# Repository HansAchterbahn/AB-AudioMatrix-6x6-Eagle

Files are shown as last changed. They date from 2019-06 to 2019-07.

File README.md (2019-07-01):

# Audio Matrix Emmelie v3.2

Active audio matrix (6x6), which can map 6 input channels to 6 output channels. Connection via 3.5 jack cable. Compatible with line signals (aux, headphones, active speakers, ...).

*Fork me and have fun!*

## Pictures

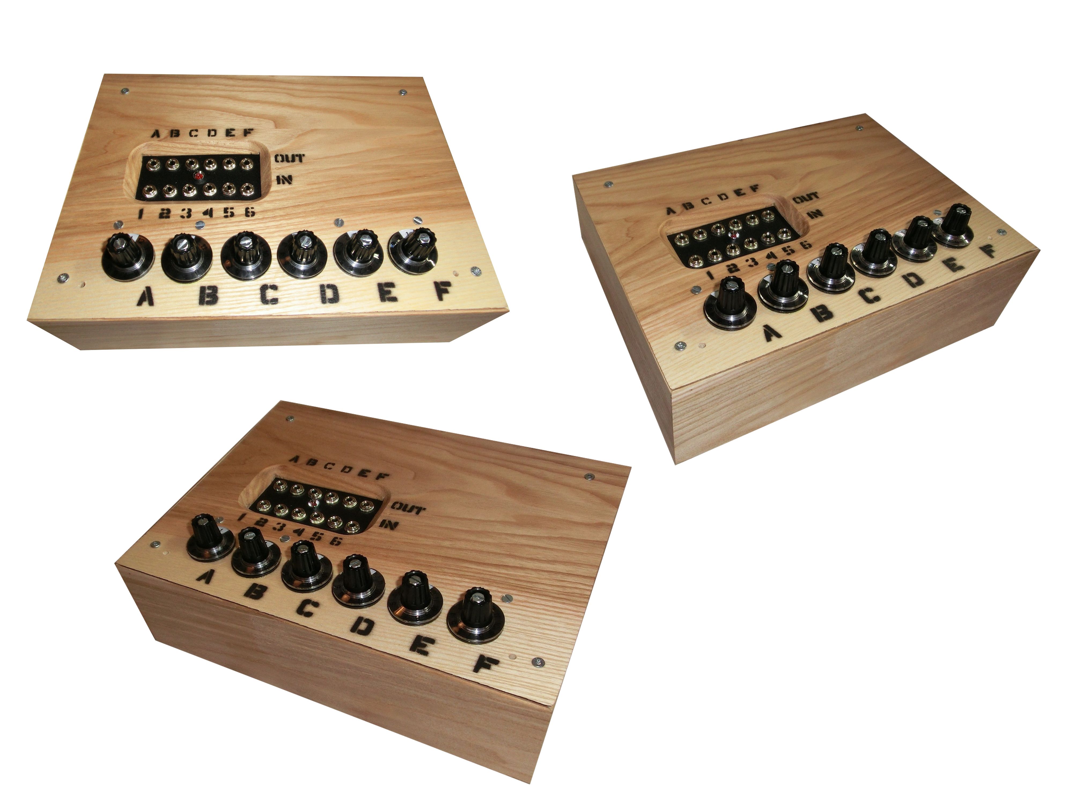
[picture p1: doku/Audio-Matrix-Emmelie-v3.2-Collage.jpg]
Foto: Collage Audio Matrix


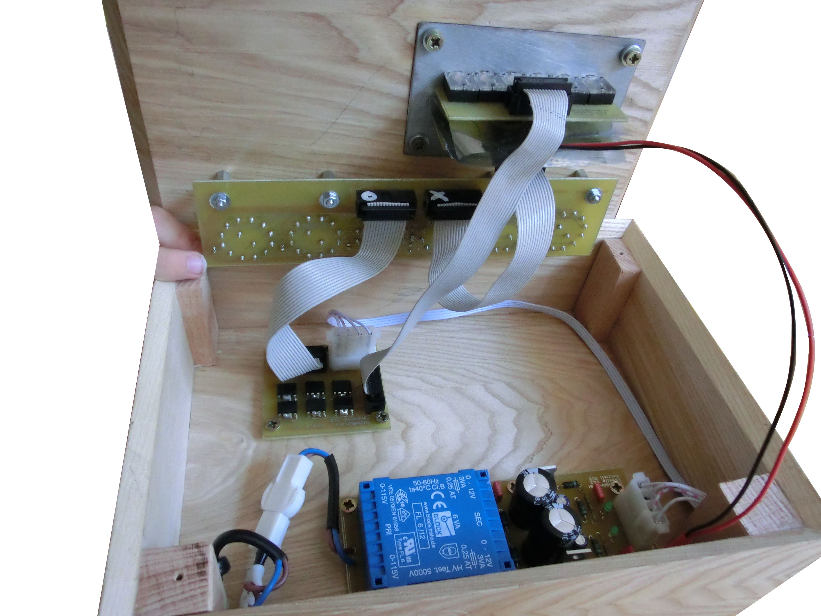
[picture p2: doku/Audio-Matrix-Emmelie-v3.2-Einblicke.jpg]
Foto: Das innere der Audio Matrix


## Schematic

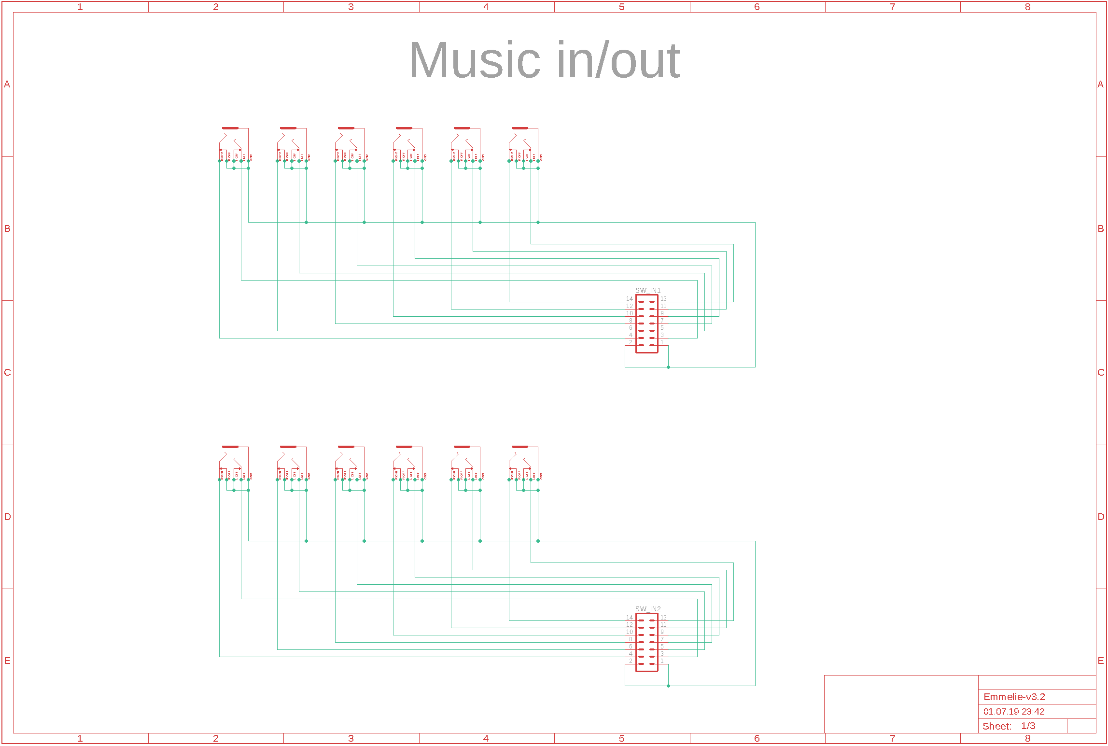
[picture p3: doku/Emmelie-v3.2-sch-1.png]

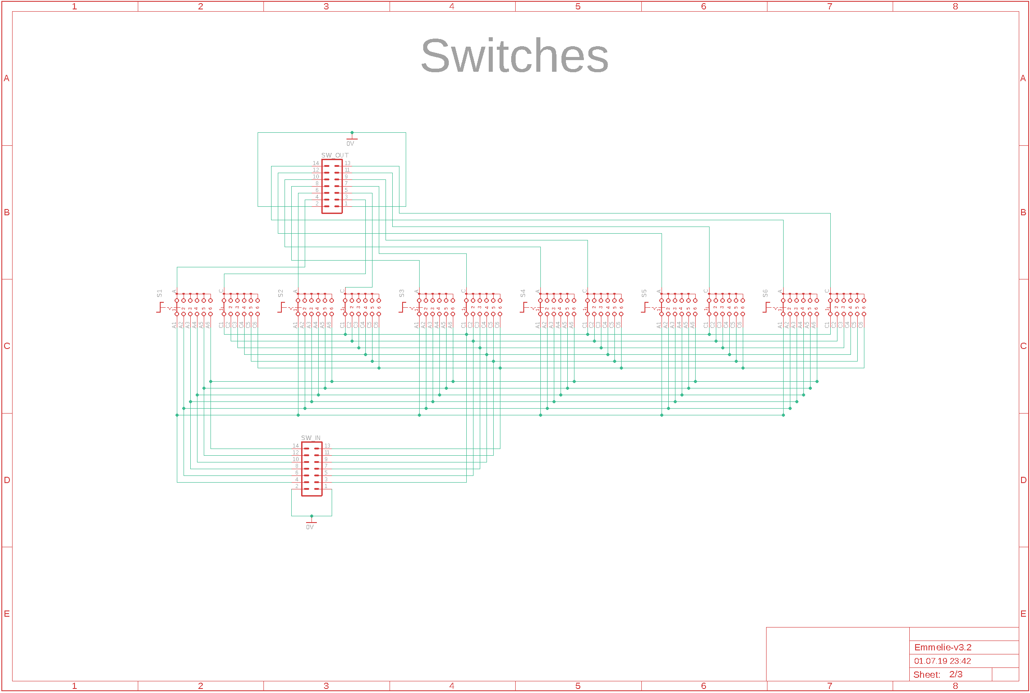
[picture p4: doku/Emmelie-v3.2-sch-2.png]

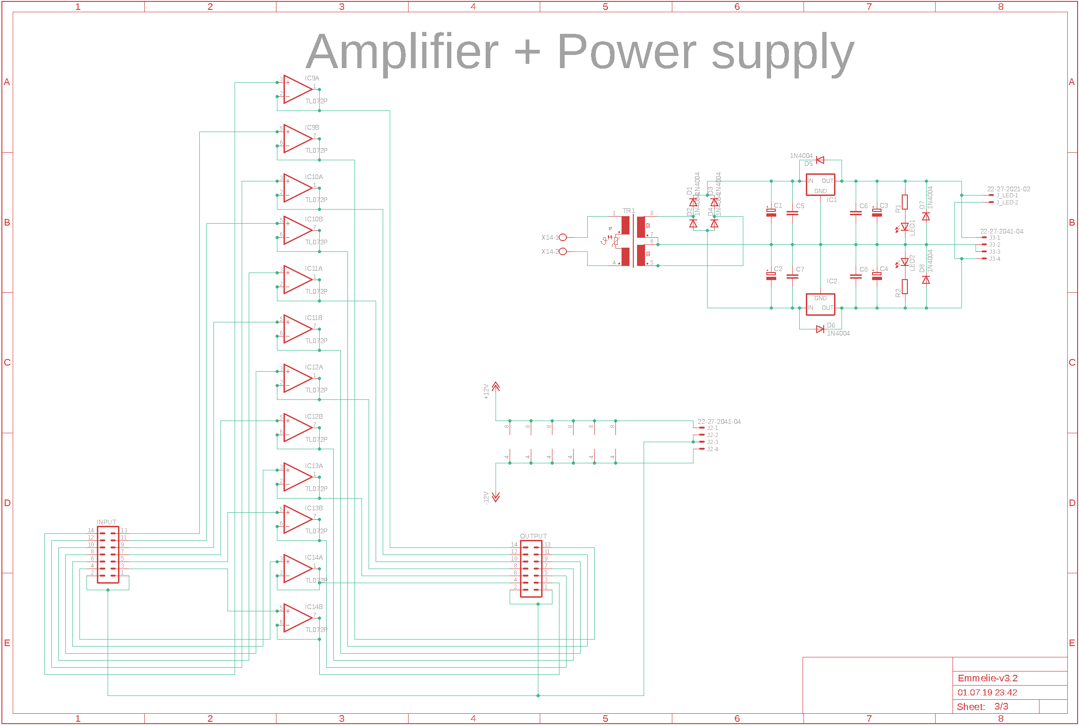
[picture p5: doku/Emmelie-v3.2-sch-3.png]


## Board

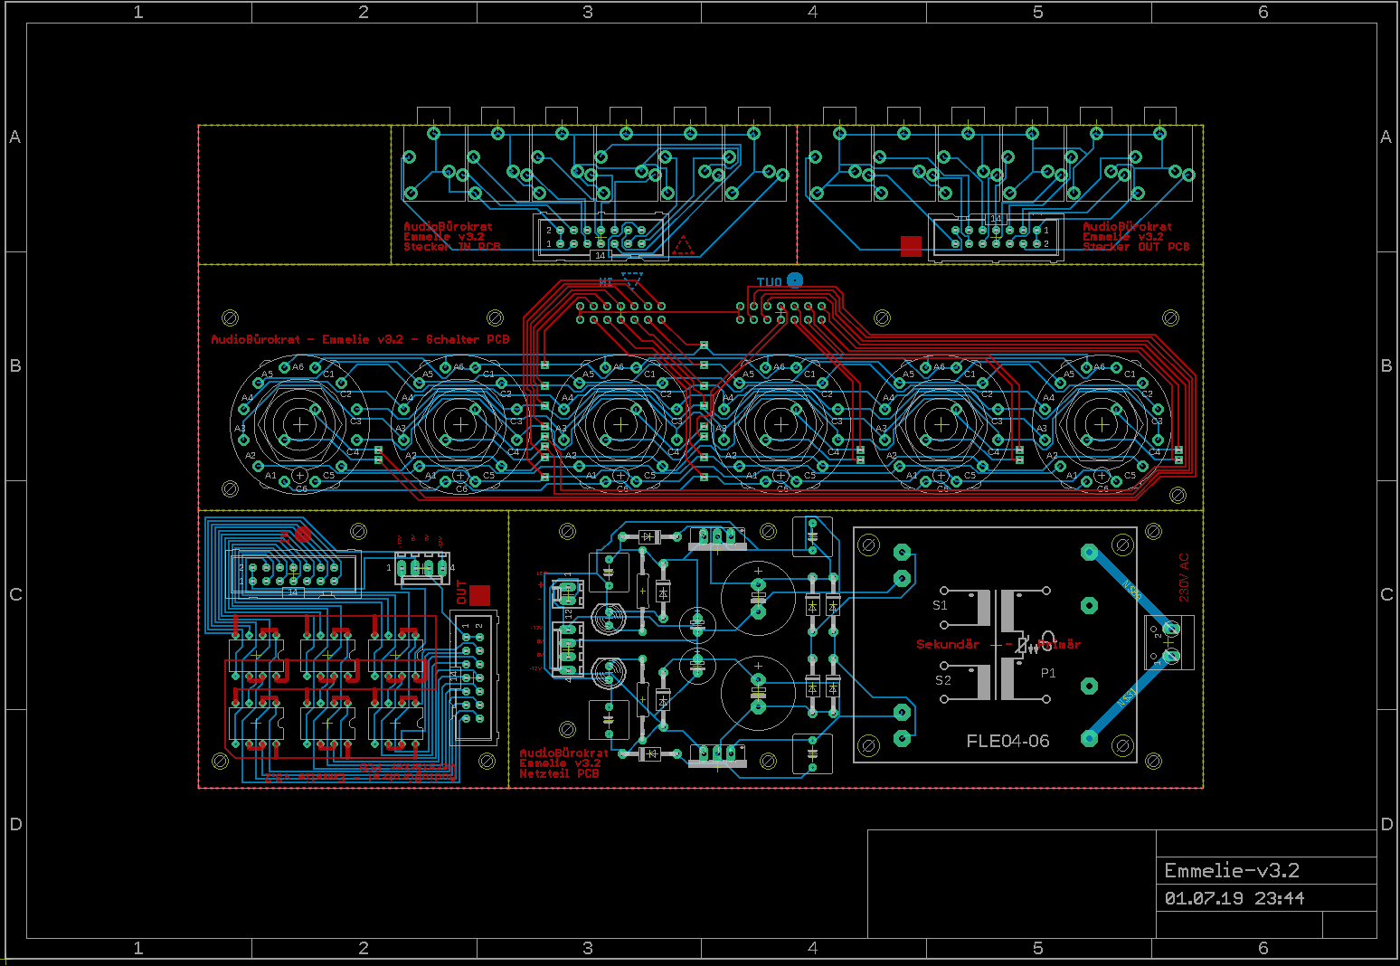
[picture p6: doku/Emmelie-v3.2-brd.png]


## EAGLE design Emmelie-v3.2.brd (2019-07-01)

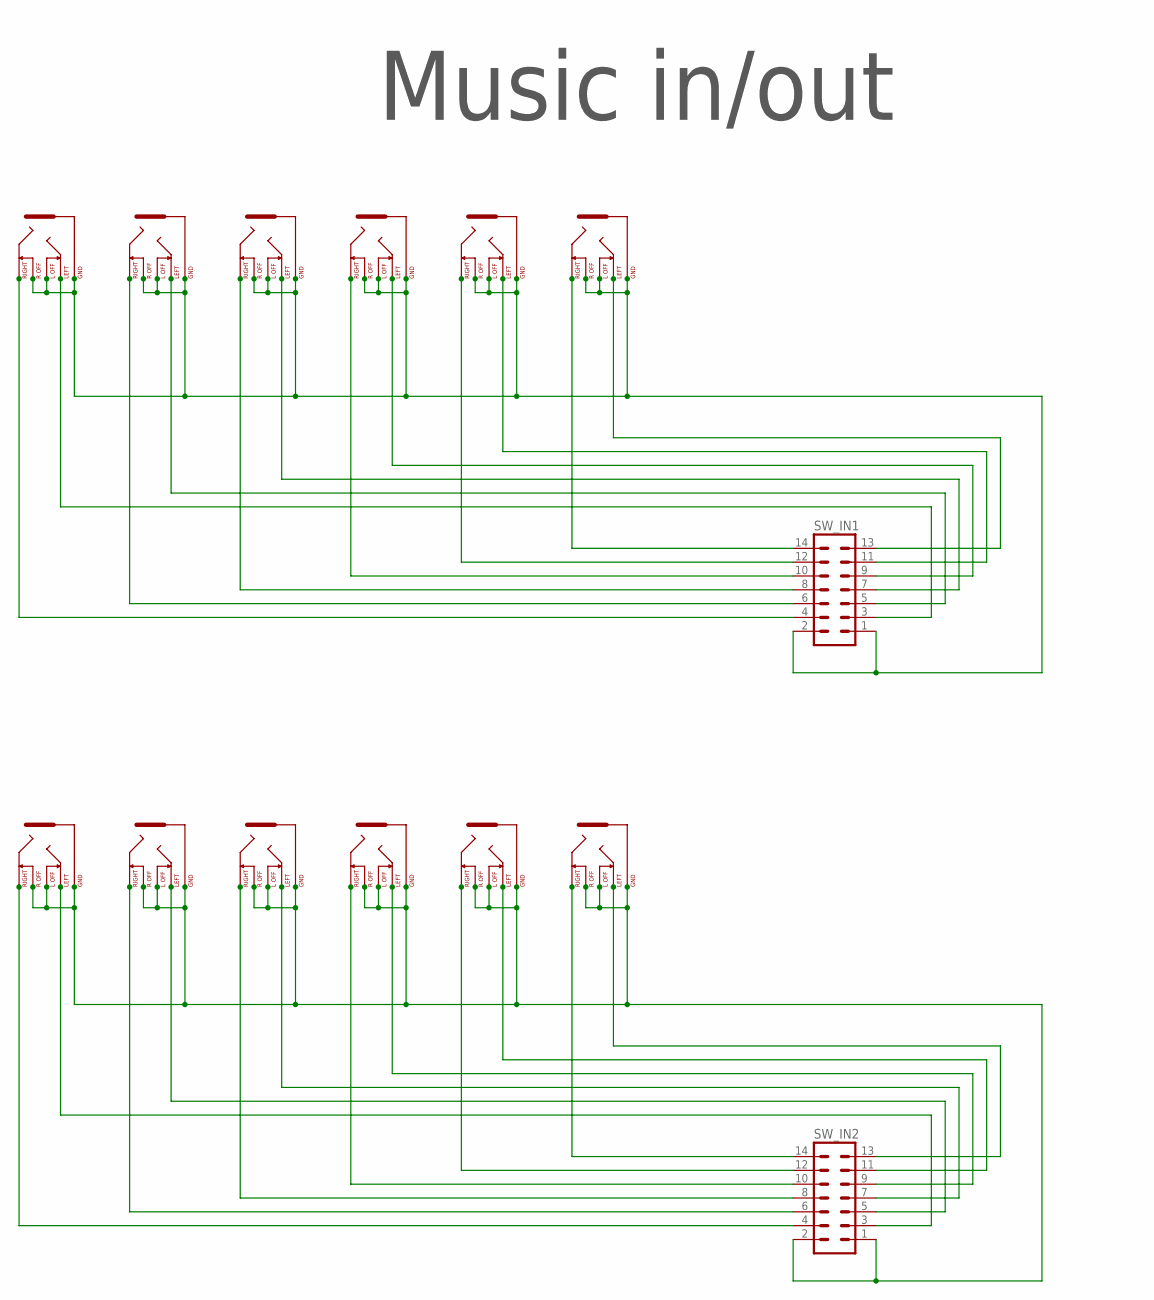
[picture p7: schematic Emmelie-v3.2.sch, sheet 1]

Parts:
SW_IN1, SW_IN2: ML14
U$1, U$2, U$3, U$4, U$5, U$6, U$7, U$8, U$9, U$10, U$11, U$12: KLINKE3,5

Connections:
KLINKE_IN_0V: SW_IN2.1, SW_IN2.2, U$7.GND, U$7.LEFT_OFF, U$7.RIGHT_OFF, U$8.GND, U$8.LEFT_OFF, U$8.RIGHT_OFF, U$9.GND, U$9.LEFT_OFF, U$9.RIGHT_OFF, U$10.GND, U$10.LEFT_OFF, U$10.RIGHT_OFF, U$11.GND, U$11.LEFT_OFF, U$11.RIGHT_OFF, U$12.GND, U$12.LEFT_OFF, U$12.RIGHT_OFF
KLINKE_OUT_0V: SW_IN1.1, SW_IN1.2, U$1.GND, U$1.LEFT_OFF, U$1.RIGHT_OFF, U$2.GND, U$2.LEFT_OFF, U$2.RIGHT_OFF, U$3.GND, U$3.LEFT_OFF, U$3.RIGHT_OFF, U$4.GND, U$4.LEFT_OFF, U$4.RIGHT_OFF, U$5.GND, U$5.LEFT_OFF, U$5.RIGHT_OFF, U$6.GND, U$6.LEFT_OFF, U$6.RIGHT_OFF
unnamed: SW_IN1.4, U$1.RIGHT
unnamed: SW_IN1.6, U$2.RIGHT
unnamed: SW_IN1.8, U$3.RIGHT
unnamed: SW_IN1.10, U$4.RIGHT
unnamed: SW_IN1.12, U$5.RIGHT
unnamed: SW_IN1.14, U$6.RIGHT
unnamed: SW_IN1.3, U$1.LEFT
unnamed: SW_IN1.5, U$2.LEFT
unnamed: SW_IN1.7, U$3.LEFT
unnamed: SW_IN1.9, U$4.LEFT
unnamed: SW_IN1.11, U$5.LEFT
unnamed: SW_IN1.13, U$6.LEFT
unnamed: SW_IN2.4, U$7.RIGHT
unnamed: SW_IN2.6, U$8.RIGHT
unnamed: SW_IN2.8, U$9.RIGHT
unnamed: SW_IN2.10, U$10.RIGHT
unnamed: SW_IN2.12, U$11.RIGHT
unnamed: SW_IN2.14, U$12.RIGHT
unnamed: SW_IN2.3, U$7.LEFT
unnamed: SW_IN2.5, U$8.LEFT
unnamed: SW_IN2.7, U$9.LEFT
unnamed: SW_IN2.9, U$10.LEFT
unnamed: SW_IN2.11, U$11.LEFT
unnamed: SW_IN2.13, U$12.LEFT

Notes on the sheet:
Music in/out

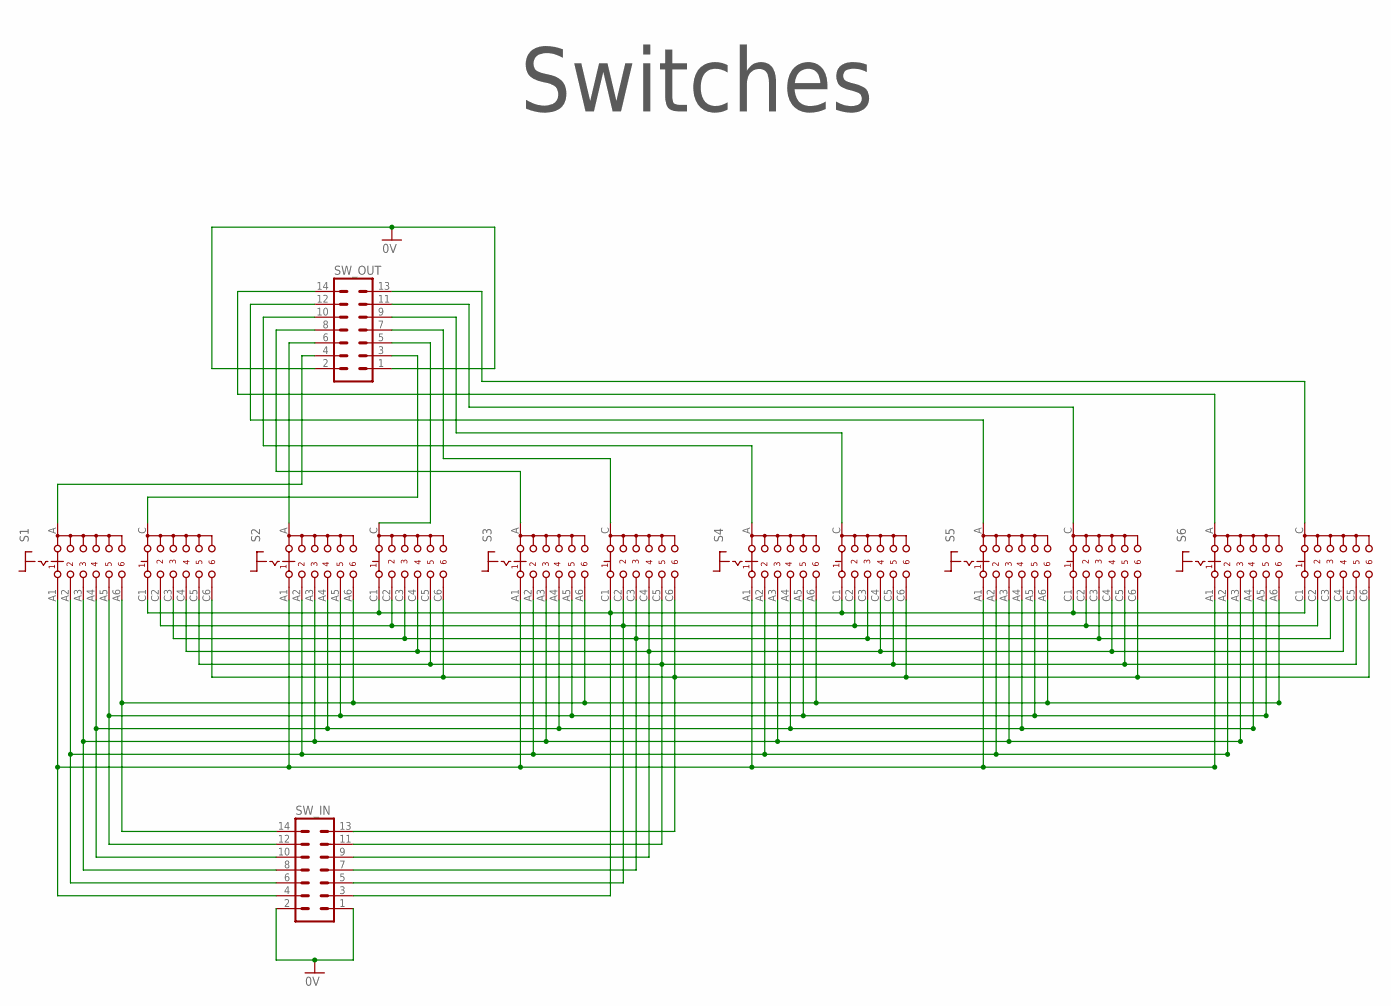
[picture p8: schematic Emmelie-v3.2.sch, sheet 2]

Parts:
S1, S2, S3, S4, S5, S6: CK102X06
SW_IN: ML14
SW_OUT: ML14

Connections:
unnamed: S1.A1, S2.A1, S3.A1, S4.A1, S5.A1, S6.A1, SW_IN.4
unnamed: S1.A2, S2.A2, S3.A2, S4.A2, S5.A2, S6.A2, SW_IN.6
unnamed: S1.A3, S2.A3, S3.A3, S4.A3, S5.A3, S6.A3, SW_IN.8
unnamed: S1.A4, S2.A4, S3.A4, S4.A4, S5.A4, S6.A4, SW_IN.10
unnamed: S1.A5, S2.A5, S3.A5, S4.A5, S5.A5, S6.A5, SW_IN.12
unnamed: S1.A6, S2.A6, S3.A6, S4.A6, S5.A6, S6.A6, SW_IN.14
unnamed: S1.C, SW_OUT.3
unnamed: S1.A, SW_OUT.4
unnamed: S2.A, SW_OUT.6
unnamed: S2.C, SW_OUT.5
unnamed: S3.A, SW_OUT.8
unnamed: S3.C, SW_OUT.7
unnamed: S4.A, SW_OUT.10
unnamed: S4.C, SW_OUT.9
unnamed: S5.A, SW_OUT.12
unnamed: S5.C, SW_OUT.11
unnamed: S6.A, SW_OUT.14
unnamed: S6.C, SW_OUT.13
unnamed: S1.C1, S2.C1, S3.C1, S4.C1, S5.C1, S6.C1, SW_IN.3
unnamed: S1.C2, S2.C2, S3.C2, S4.C2, S5.C2, S6.C2, SW_IN.5
unnamed: S1.C3, S2.C3, S3.C3, S4.C3, S5.C3, S6.C3, SW_IN.7
unnamed: S1.C4, S2.C4, S3.C4, S4.C4, S5.C4, S6.C4, SW_IN.9
unnamed: S1.C5, S2.C5, S3.C5, S4.C5, S5.C5, S6.C5, SW_IN.11
unnamed: S1.C6, S2.C6, S3.C6, S4.C6, S5.C6, S6.C6, SW_IN.13
SCHALTER_0V: SW_IN.1, SW_IN.2, SW_OUT.1, SW_OUT.2

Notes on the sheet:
Switches

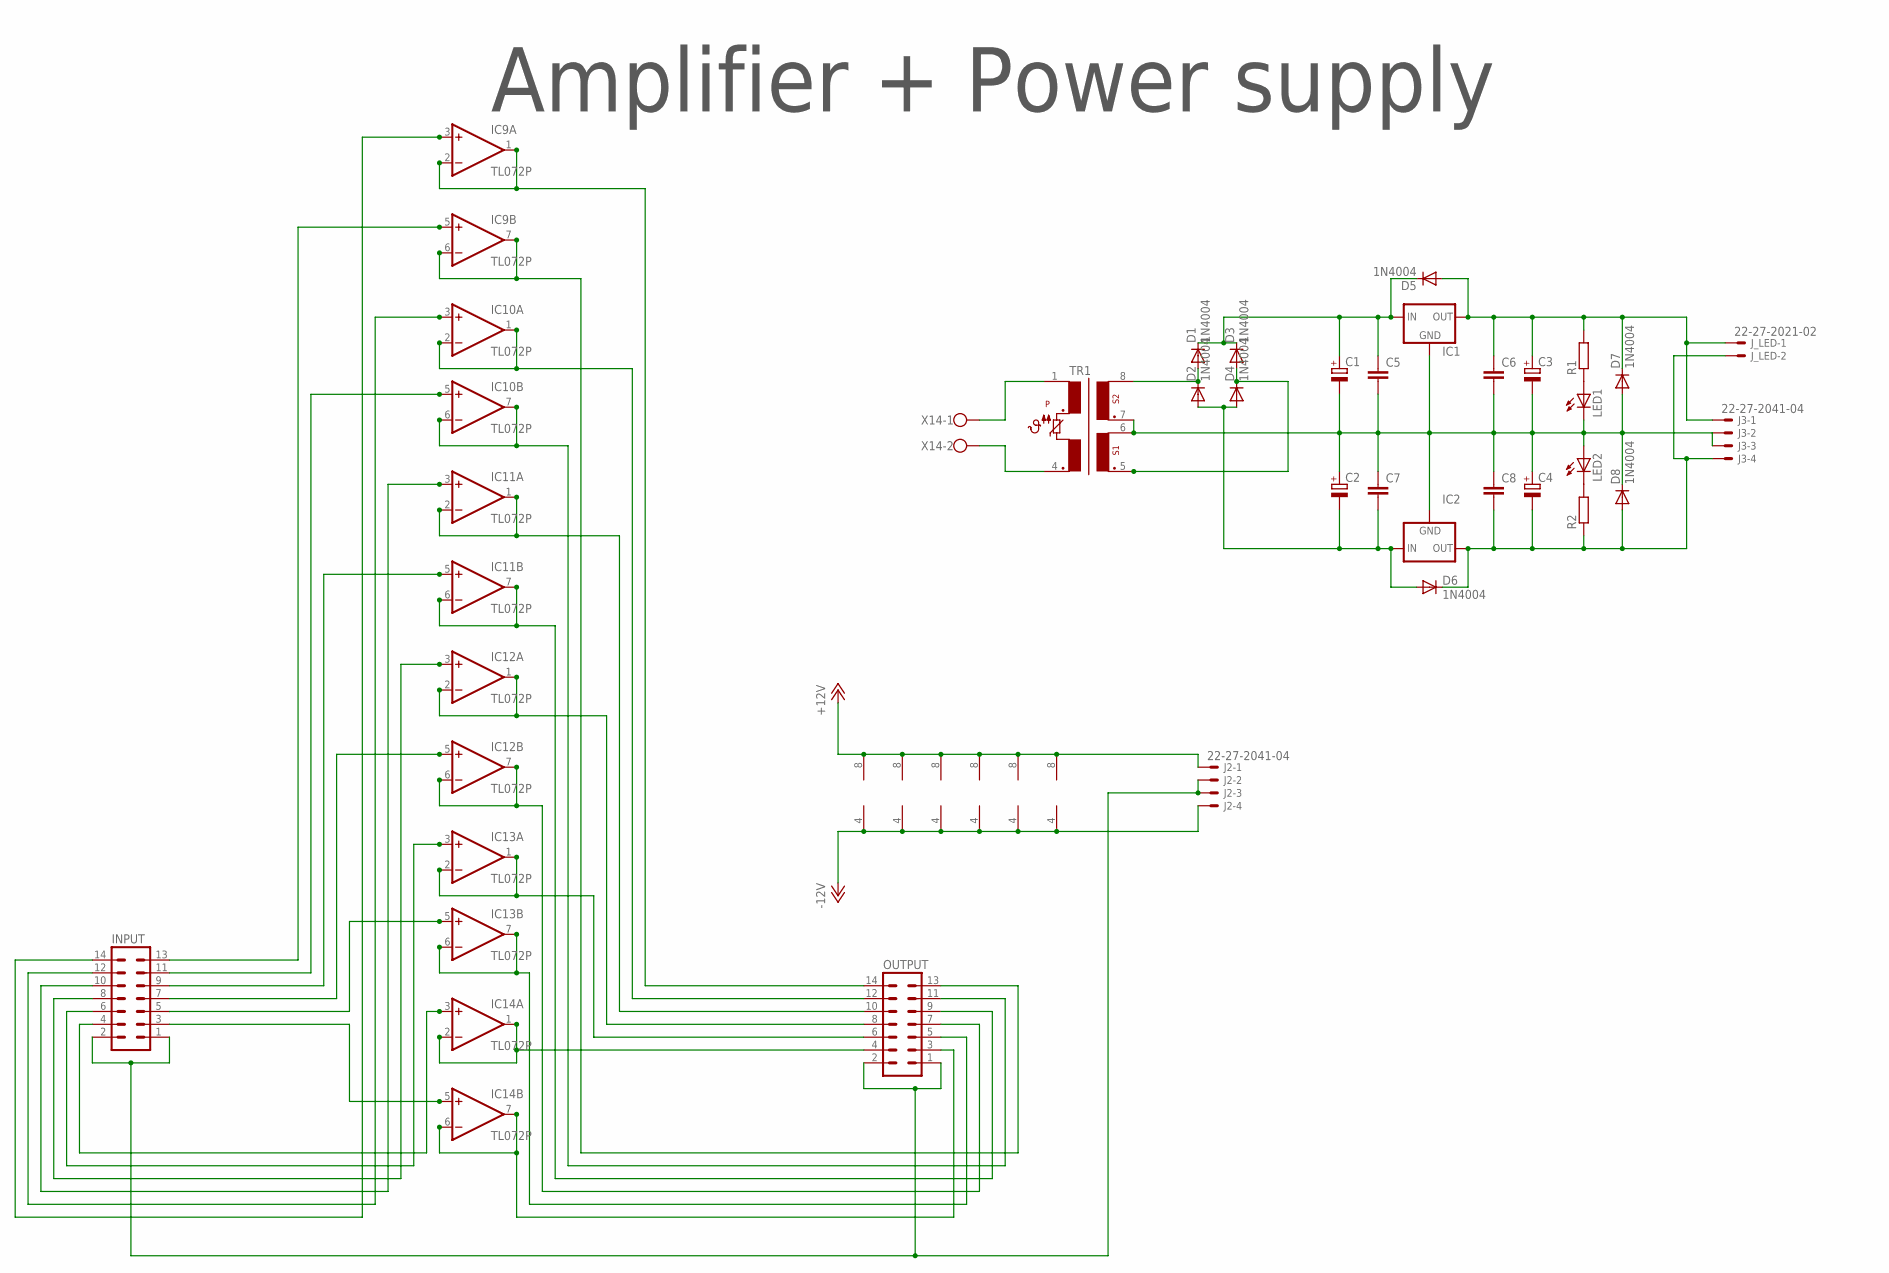
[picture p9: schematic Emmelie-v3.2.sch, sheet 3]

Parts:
C1, C2: CPOL-EUE5-13; E5-13
C3, C4: CPOL-EUE2.5-7; E2,5-7
C5, C6, C7, C8: C-EU050-075X075; C050-075X075
D1, D2, D3, D4, D5, D6, D7, D8: 1N4004; DO41-10
IC1: 78XXS
IC2: 79XXS
IC9, IC10, IC11, IC12, IC13, IC14: TL072P; DIL08
INPUT: ML14
J2, J3: 22-27-2041-04; 6410-04
J_LED: 22-27-2021-02; 6410-02
LED1, LED2: LED5MM
OUTPUT: ML14
R1, R2: R-EU_0207/15; 0207/15
TR1: FLE04-06
X14: W237-02P; W237-132

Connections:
+12V: IC9.8 (V+), IC10.8 (V+), IC11.8 (V+), IC12.8 (V+), IC13.8 (V+), IC14.8 (V+), J2.1
-12V: IC9.4 (V-), IC10.4 (V-), IC11.4 (V-), IC12.4 (V-), IC13.4 (V-), IC14.4 (V-), J2.4
unnamed: C2.-, C7.2, D2.A, D4.A, D6.A, IC2.IN
unnamed: D3.A, D4.C, TR1.5
unnamed: C1.+, C5.1, D1.C, D3.C, D5.C, IC1.IN
unnamed: LED1.A, R1.1
unnamed: LED2.K (C), R2.2
unnamed: TR1.1, X14.1
unnamed: D1.A, D2.C, TR1.8
unnamed: C3.+, C6.1, D5.A, D7.C, IC1.OUT, J3.1, J_LED.1, R1.2
unnamed: C4.-, C8.2, D6.C, D8.A, IC2.OUT, J3.4, J_LED.2, R2.1
unnamed: IC14.5 (+IN), INPUT.3
unnamed: IC14.3 (+IN), INPUT.4
unnamed: IC13.3 (+IN), INPUT.6
unnamed: IC12.3 (+IN), INPUT.8
unnamed: IC9.3 (+IN), INPUT.14
unnamed: IC12.5 (+IN), INPUT.7
unnamed: IC10.3 (+IN), INPUT.12
unnamed: IC13.5 (+IN), INPUT.5
unnamed: IC11.5 (+IN), INPUT.9
unnamed: IC11.3 (+IN), INPUT.10
unnamed: IC10.5 (+IN), INPUT.11
unnamed: IC9.5 (+IN), INPUT.13
unnamed: IC14.6 (-IN), IC14.7 (OUT), OUTPUT.3
unnamed: IC14.1 (OUT), IC14.2 (-IN), OUTPUT.4
unnamed: IC13.6 (-IN), IC13.7 (OUT), OUTPUT.5
unnamed: IC13.1 (OUT), IC13.2 (-IN), OUTPUT.6
unnamed: IC12.6 (-IN), IC12.7 (OUT), OUTPUT.7
unnamed: IC12.1 (OUT), IC12.2 (-IN), OUTPUT.8
unnamed: IC11.6 (-IN), IC11.7 (OUT), OUTPUT.9
unnamed: IC11.1 (OUT), IC11.2 (-IN), OUTPUT.10
unnamed: IC10.6 (-IN), IC10.7 (OUT), OUTPUT.11
unnamed: IC10.1 (OUT), IC10.2 (-IN), OUTPUT.12
unnamed: IC9.6 (-IN), IC9.7 (OUT), OUTPUT.13
unnamed: IC9.1 (OUT), IC9.2 (-IN), OUTPUT.14
unnamed: TR1.4, X14.2
NETZ_0V: C1.-, C2.+, C3.-, C4.+, C5.2, C6.2, C7.1, C8.1, D7.A, D8.C, IC1.GND, IC2.GND, J3.2, J3.3, LED1.K (C), LED2.A, TR1.6, TR1.7
OPV_0V: INPUT.1, INPUT.2, J2.2, J2.3, OUTPUT.1, OUTPUT.2

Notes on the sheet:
Amplifier + Power supply

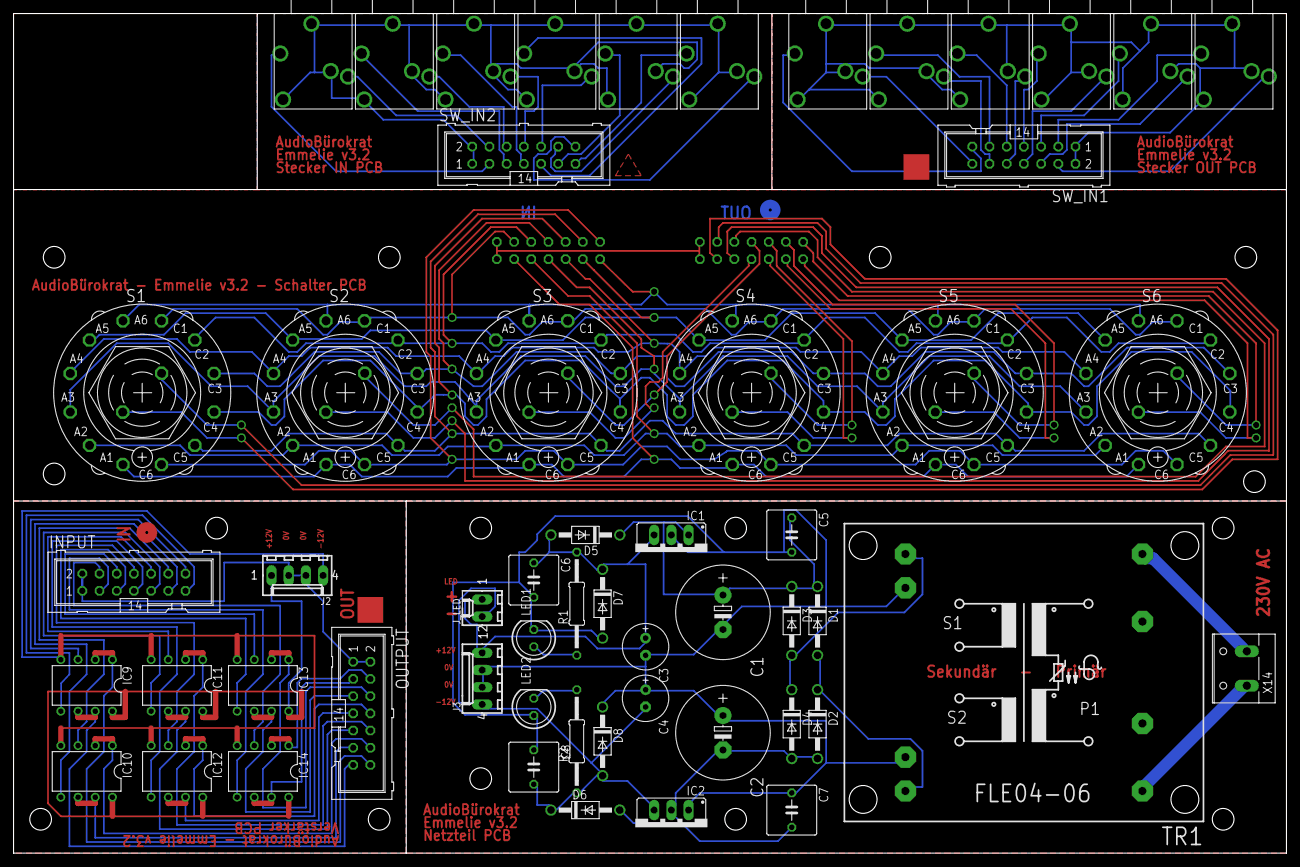
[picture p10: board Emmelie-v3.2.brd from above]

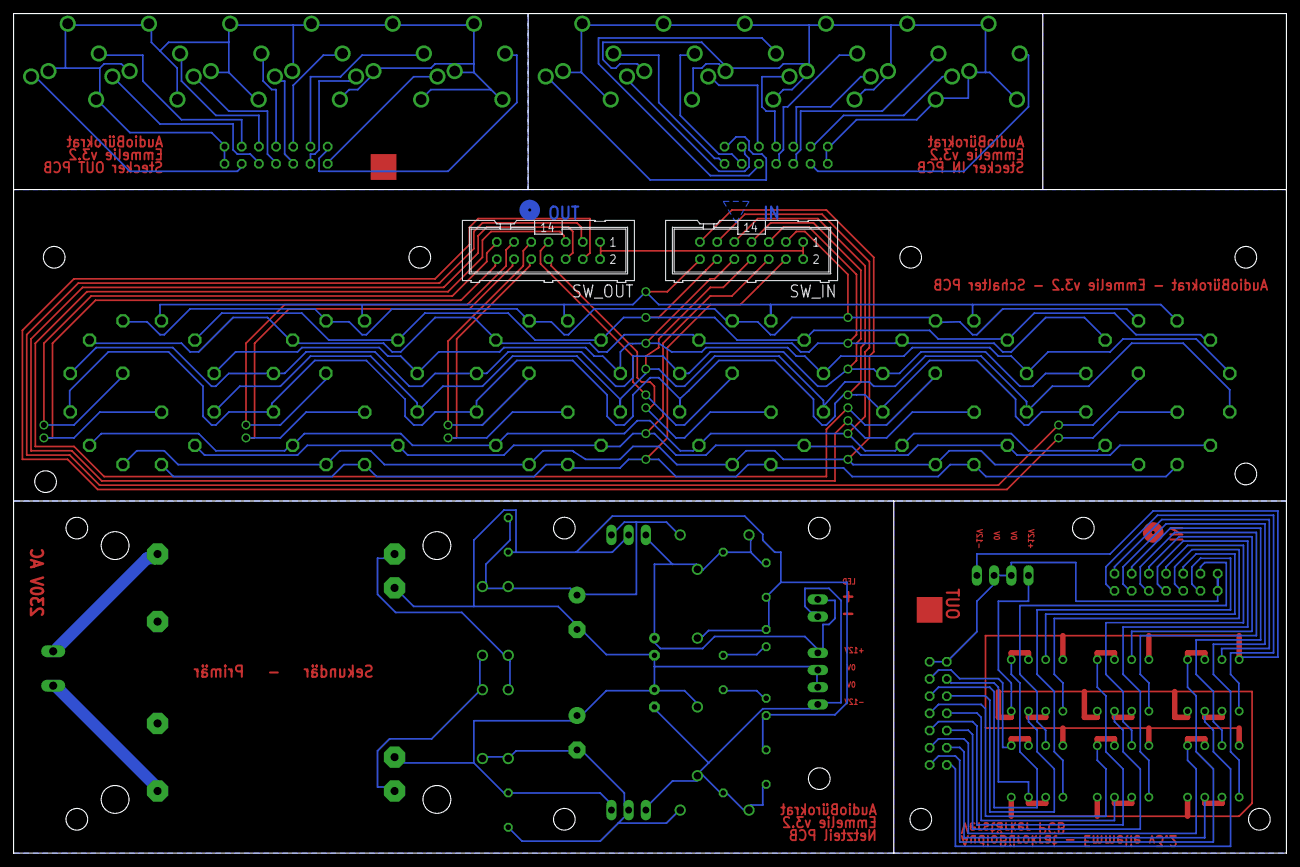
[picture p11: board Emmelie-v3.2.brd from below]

Board: 2 copper layers, 188.0 x 124.0 mm, 58 parts (2 on the bottom side), 89 nets.

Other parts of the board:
U$13: A4L-LOC

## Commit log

2019-03-22 Vorlage aus Emmelie-v3.1 von MH kopiert
    [Emmelie-v3.2.brd, Emmelie-v3.2.sch]
2019-03-22 Optimierung für nicht durchkontaktierte Platinen
    [Emmelie-v3.2.brd, Emmelie-v3.2.sch]
2019-03-22 Korrektur OPV PBC
    [Emmelie-v3.2.brd, Emmelie-v3.2.sch]
2019-03-22 Korrektur OPV PBC 2
    [Emmelie-v3.2.brd, Emmelie-v3.2.sch]
2019-03-22 Korrektur Folienkondensator Netzplatine
    [Emmelie-v3.2.brd, Emmelie-v3.2.sch]
2019-03-22 Korrektur 12V + 230V Stecker
    [Emmelie-v3.2.brd, Emmelie-v3.2.sch]
2019-03-22 Korrektur Stecker-Zuordnung
    [Emmelie-v3.2.brd, Emmelie-v3.2.sch]
2019-03-22 Korrektur Klinken
    [Emmelie-v3.2.brd, Emmelie-v3.2.sch]
2019-03-22 Korrektur Klinken 2
    [Emmelie-v3.2.brd, Emmelie-v3.2.sch]
2019-03-22 Polygon 2
    [Emmelie-v3.2.brd, Emmelie-v3.2.sch]
2019-06-08 Old Eagle data converted to new Eagle XML data standard
    [Emmelie-v3.2.brd, Emmelie-v3.2.sch]
2019-07-01 tidied up a little in schematic and board
    [Emmelie-v3.2.brd, Emmelie-v3.2.sch]
2019-07-01 Update README | added images of schematic and board
